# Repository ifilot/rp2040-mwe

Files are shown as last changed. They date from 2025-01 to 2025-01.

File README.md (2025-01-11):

# RP2040 Minimal Working Example

Slightly adjusted version of the [minimal design example](
https://datasheets.raspberrypi.com/rp2040/hardware-design-with-rp2040.pdf)
of Raspberry Pi LTD. Components have been added for the assembly service
of JLCPCB, choosing - where possible - as many basic components to save
costs.

BOM and placement files as well as the GERBER files are added available
for easy ordering.

> [!IMPORTANT]
> I did not design this PCB. I merely added the part IDs for JLCPCB and
> generated the BOM and CPL files. The original designs are made by
> Raspberry Pi LTD and it is highly recommended to always check their
> website for the latest version. See the link above.

## Files

* [GERBER files (zip)](RP2040_minimal_r2/GERBERS/RP2040_minimal.zip)
* [Bill of Materials](RP2040_minimal_r2/production/bom.csv)
* [Placement file](RP2040_minimal_r2/production/positions.csv)

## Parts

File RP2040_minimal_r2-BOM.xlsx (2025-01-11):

RP2040_minimal_r2 BOM
Item | Quantity | Reference | Part | Voltage | Current | Power | Material | Size | Tolerance | Manufacturer | Manuf. Part # | Description | Notes
1 | 3 | C1,C4,C17 | 10u | 16V |  |  | X5R | 0805_2012Metric | 10% | Murata | GRM21BR61C106KE15K | CAP CER 10UF 16V X5R 0805 | Or equivalent
2 | 2 | C2, C3 | 15p | 50V |  |  | C0G | 0402_1005Metric | 5% | Murata | GCM1555C1H150JA16D | CAP CER 15PF 50V C0G/NP0 0402 | Or equivalent
3 | 10 | C5, C6, C7, C9, C11, C12, C13, C14, C15, C16 | 100n | 25V |  |  | X7R | 0402_1005Metric | 10% | Murata | GRM155R71E104KE14J | CAP CER 0.1UF 25V X7R 0402 | Or equivalent
4 | 2 | C8, C10 | 1u | 10V |  |  | X6S | 0402_1005Metric | 10% | Murata | GRM155C81A105KA12D | CAP CER 1UF 10V X6S 0402 | Or equivalent
5 | 1 | J1 | USB_B_Micro |  |  |  |  |  |  | Amphenol | 10103594-0001LF | CONN RCPT USB2.0 MICRO B SMD R/A | Or equivalent
6 | 1 | J2 | 1x2 way header |  |  |  |  |  |  | Samtec | TSW-102-23-T-S | 2.54mm pin header 1x2 | Or equivalent
7 | 2 | J3, J4 | 2x18 way header |  |  |  |  |  |  | Samtec | TSW-118-23-T-D | 2.54mm pin header 2x18 | Or equivalent
8 | 2 | R1, R5 | 1k |  |  | 63mW |  | 0402_1005Metric | 1% | Yageo | RC0402FR-071KP | RES SMD 1K OHM 1% 1/16W 0402 | Or equivalent
9 | 1 | R2 | DNF |  |  |  |  | 0402_1005Metric |  |  |  |  | Do Not Fit
10 | 2 | R3, R4 | 27.4 |  |  | 63mW |  | 0402_1005Metric | 1% | Yageo | RC0402FR-0727R4L | RES SMD 27.4 OHM 1% 1/16W 0402 | Or equivalent
11 | 1 | U1 | NCP1117-3.3 |  |  |  |  | SOT-223-3 |  | ON Semiconductor | NCP1117ST33T3G | IC REG LINEAR 3.3V 1A SOT223
12 | 1 | U2 | W25Q128JVS |  |  |  |  | SOIC-8 |  | Winbond | W25Q128JVSIQ TR | IC FLASH 128M SPI 133MHZ 8SOIC
13 | 1 | U3 | RP2040 |  |  |  |  | QFN56 |  | Raspberry Pi | RP2040
14 | 1 | Y1 | ABM8-272-T3 |  |  |  |  | SMD_3225 |  | Abracon | ABM8-272-T3 | CRYSTAL 12.0000MHZ 3.2x2.5MM SMD

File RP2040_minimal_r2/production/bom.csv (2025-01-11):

Designator | Footprint | Quantity | Value | LCSC Part #
C1, C17, C4 | 0805 | 3 | 10u | C15850
C10, C8 | 0402 | 2 | 1u | C52923
C11, C12, C13, C14, C15, C16, C5, C6, C7, C9 | 0402 | 10 | 100n | C307331
C2, C3 | 0402 | 2 | 15p | C1548
J1 | USB_Micro-B_Amphenol_10103594-0001LF_Horizontal_modified | 1 | USB_B_Micro | C428495
R1, R5 | 0402 | 2 | 1k | C11702
R3, R4 | 0402 | 2 | 27 | C274349
U1 | SOT-223-3_TabPin2 | 1 | NCP1117-3.3_SOT223 | C26537
U2 | SOIC-8_5.23x5.23mm_P1.27mm | 1 | W25Q128JVS | C97521
U3 | RP2040-QFN-56 | 1 | RP2040 | C2040
Y1 | Crystal_SMD_3225-4Pin_3.2x2.5mm | 1 | ABM8-272-T3 | C20625731

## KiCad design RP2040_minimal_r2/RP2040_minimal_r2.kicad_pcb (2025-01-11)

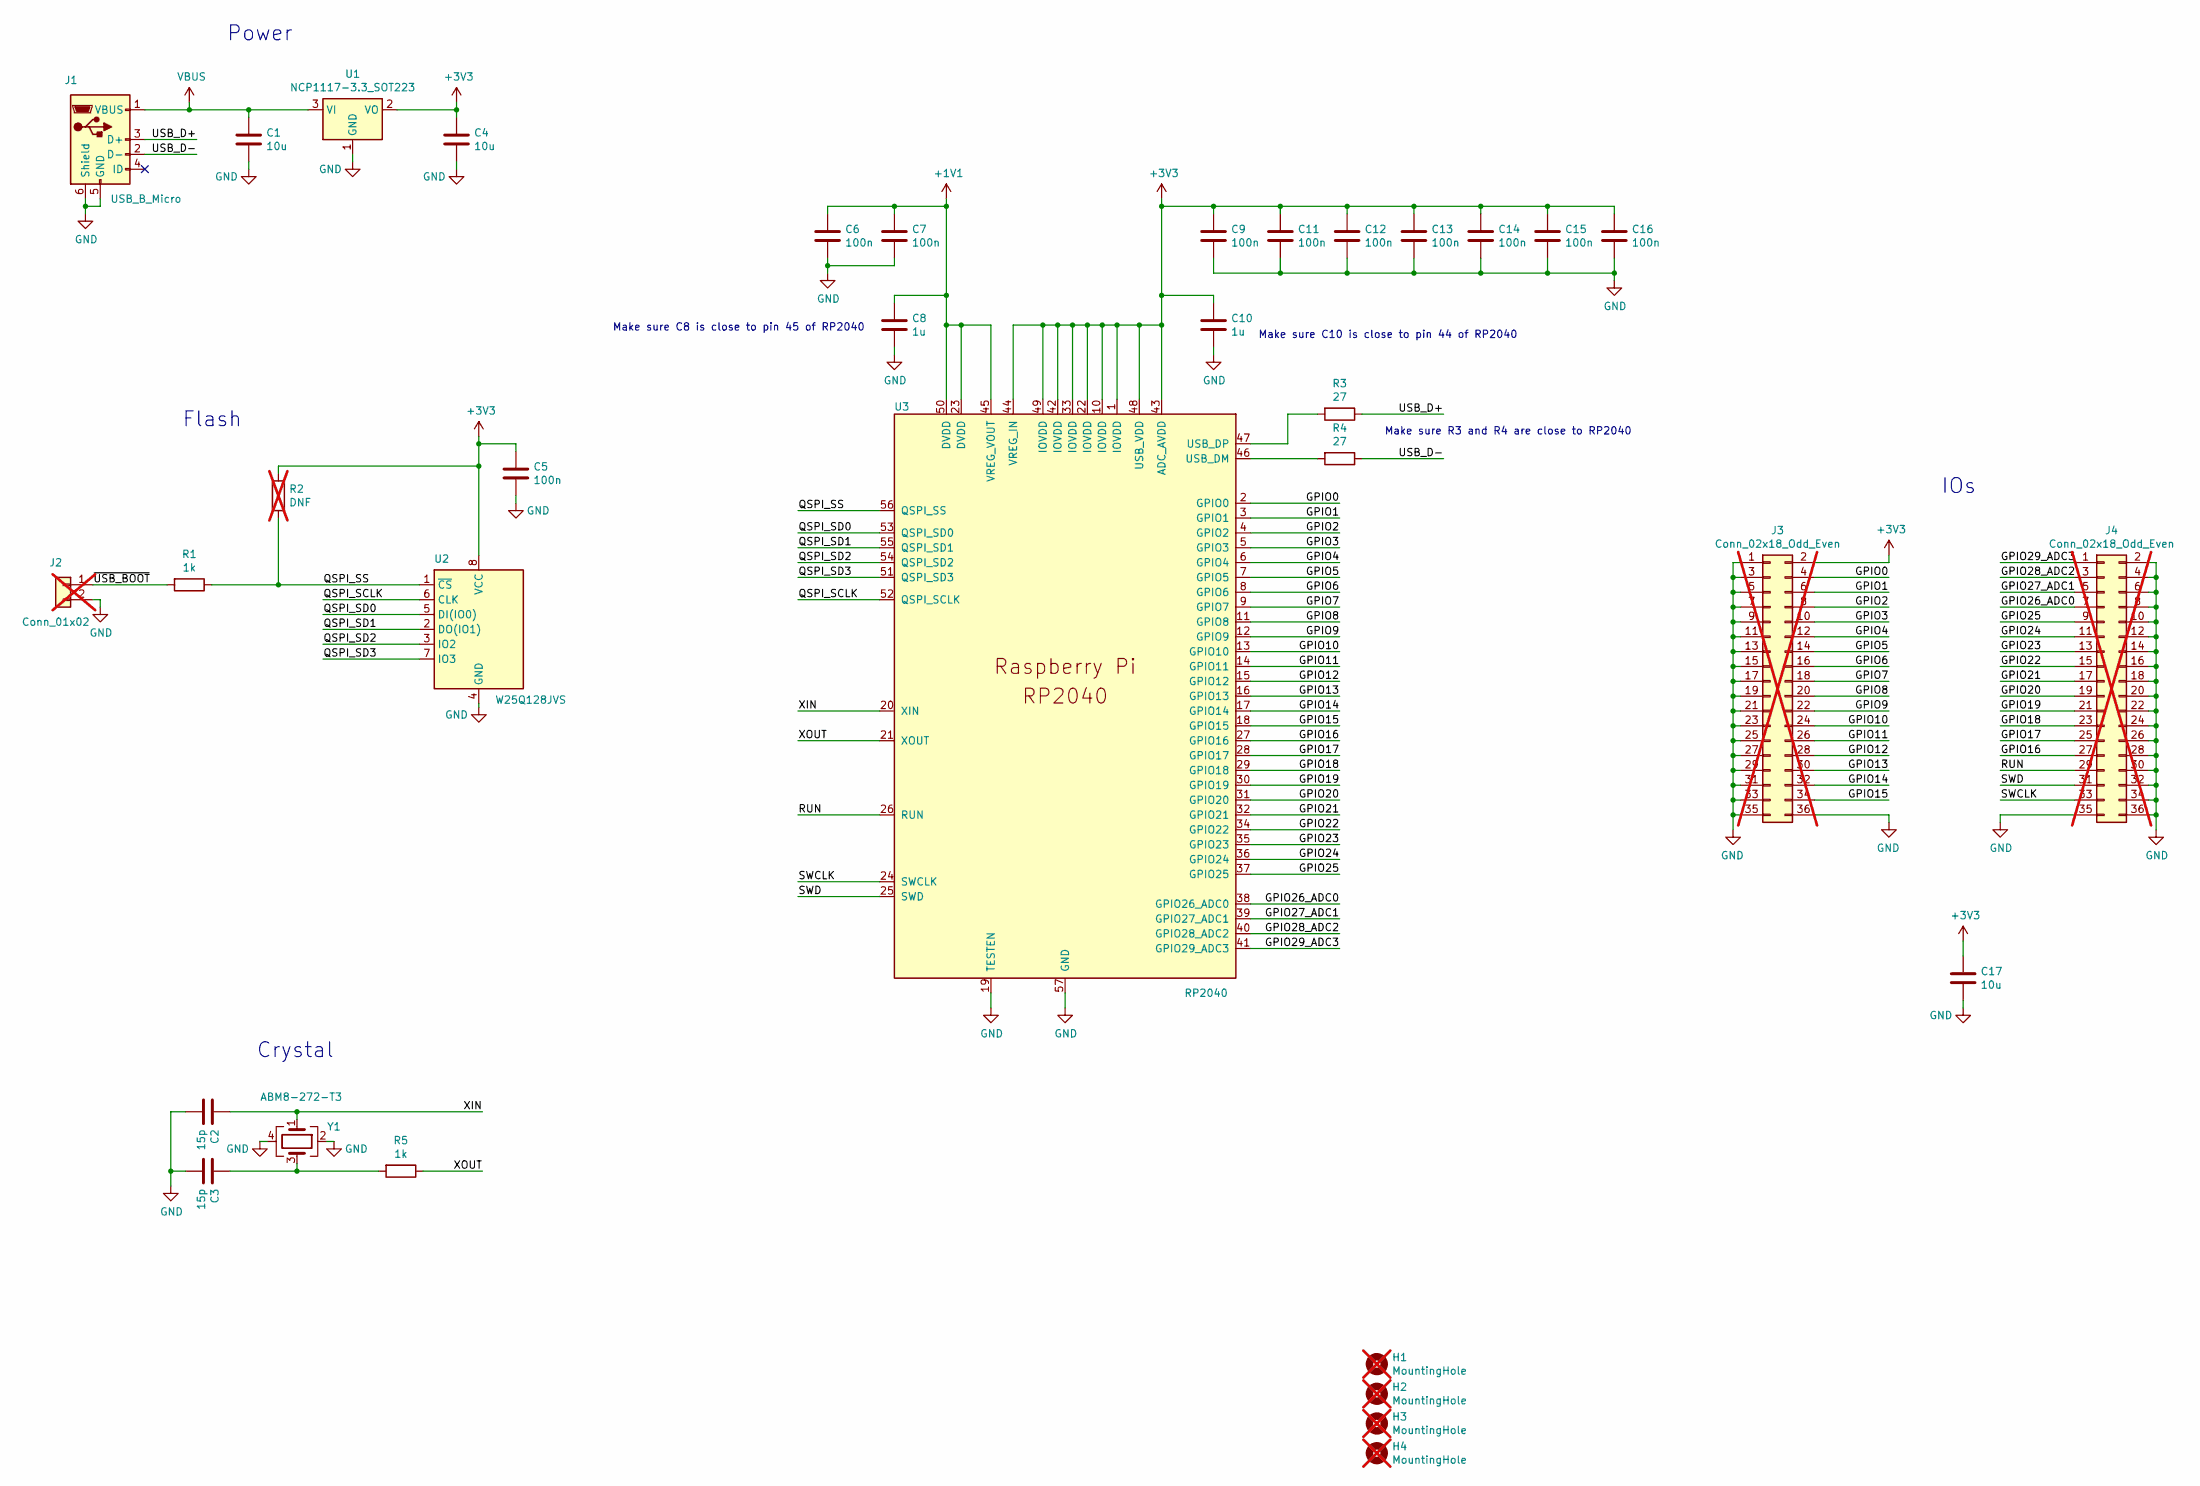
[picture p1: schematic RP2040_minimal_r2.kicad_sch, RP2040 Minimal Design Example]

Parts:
C1, C4, C17: 10u; C_0805_2012Metric; LCSC C15850
C2, C3: 15p; C_0402_1005Metric; LCSC C1548
C5, C6, C7, C9, C11, C12, C13, C14, C15, C16: 100n; C_0402_1005Metric; LCSC C307331
C8, C10: 1u; C_0402_1005Metric; LCSC C52923
H1, H2, H3, H4: MountingHole; MountingHole_2.7mm_M2.5; not fitted
J1: USB_B_Micro; USB_Micro-B_Amphenol_10103594-0001LF_Horizontal_modified; LCSC C428495
J2: Conn_01x02; PinHeader_1x02_P2.54mm_Vertical; not fitted
J3, J4: Conn_02x18_Odd_Even; PinHeader_2x18_P2.54mm_Vertical; not fitted
R1, R5: 1k; R_0402_1005Metric; LCSC C11702
R2: DNF; R_0402_1005Metric; not fitted
R3, R4: 27; R_0402_1005Metric; LCSC C274349
U1: NCP1117-3.3_SOT223; SOT-223-3_TabPin2; LCSC C6186
U2: W25Q128JVS; SOIC-8_5.23x5.23mm_P1.27mm; LCSC C97521
U3: RP2040; RP2040-QFN-56; LCSC C2040
Y1: ABM8-272-T3; Crystal_SMD_3225-4Pin_3.2x2.5mm; LCSC C20625731

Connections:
+1V1: C6.1, C7.1, C8.1, U3.23 (DVDD), U3.45 (VREG_VOUT), U3.50 (DVDD)
+3V3: C4.1, C5.1, C9.1, C10.1, C11.1, C12.1, C13.1, C14.1, C15.1, C16.1, C17.1, J3.2, R2.1, U1.2 (VO), U2.8 (VCC), U3.1 (IOVDD), U3.10 (IOVDD), U3.22 (IOVDD), U3.33 (IOVDD), U3.42 (IOVDD), U3.43 (ADC_AVDD), U3.44 (VREG_IN), U3.48 (USB_VDD), U3.49 (IOVDD)
/GPIO0: J3.4, U3.2 (GPIO0)
/GPIO1: J3.6, U3.3 (GPIO1)
/GPIO2: J3.8, U3.4 (GPIO2)
/GPIO3: J3.10, U3.5 (GPIO3)
/GPIO4: J3.12, U3.6 (GPIO4)
/GPIO5: J3.14, U3.7 (GPIO5)
/GPIO6: J3.16, U3.8 (GPIO6)
/GPIO7: J3.18, U3.9 (GPIO7)
/GPIO8: J3.20, U3.11 (GPIO8)
/GPIO9: J3.22, U3.12 (GPIO9)
/GPIO10: J3.24, U3.13 (GPIO10)
/GPIO11: J3.26, U3.14 (GPIO11)
/GPIO12: J3.28, U3.15 (GPIO12)
/GPIO13: J3.30, U3.16 (GPIO13)
/GPIO14: J3.32, U3.17 (GPIO14)
/GPIO15: J3.34, U3.18 (GPIO15)
/GPIO16: J4.27, U3.27 (GPIO16)
/GPIO17: J4.25, U3.28 (GPIO17)
/GPIO18: J4.23, U3.29 (GPIO18)
/GPIO19: J4.21, U3.30 (GPIO19)
/GPIO20: J4.19, U3.31 (GPIO20)
/GPIO21: J4.17, U3.32 (GPIO21)
/GPIO22: J4.15, U3.34 (GPIO22)
/GPIO23: J4.13, U3.35 (GPIO23)
/GPIO24: J4.11, U3.36 (GPIO24)
/GPIO25: J4.9, U3.37 (GPIO25)
/GPIO26_ADC0: J4.7, U3.38 (GPIO26_ADC0)
/GPIO27_ADC1: J4.5, U3.39 (GPIO27_ADC1)
/GPIO28_ADC2: J4.3, U3.40 (GPIO28_ADC2)
/GPIO29_ADC3: J4.1, U3.41 (GPIO29_ADC3)
/QSPI_SCLK: U2.6 (CLK), U3.52 (QSPI_SCLK)
/QSPI_SD0: U2.5 (DI(IO0)), U3.53 (QSPI_SD0)
/QSPI_SD1: U2.2 (DO(IO1)), U3.55 (QSPI_SD1)
/QSPI_SD2: U2.3 (IO2), U3.54 (QSPI_SD2)
/QSPI_SD3: U2.7 (IO3), U3.51 (QSPI_SD3)
/QSPI_SS: R1.1, R2.2, U2.1 (~CS), U3.56 (QSPI_SS)
/RUN: J4.29, U3.26 (RUN)
/SWCLK: J4.33, U3.24 (SWCLK)
/SWD: J4.31, U3.25 (SWD)
/USB_D+: J1.3 (D+), R3.1
/USB_D-: J1.2 (D-), R4.1
/XIN: C2.1, U3.20 (XIN), Y1.1
/XOUT: R5.1, U3.21 (XOUT)
/~USB_BOOT: J2.1, R1.2
GND: C1.2, C2.2, C3.2, C4.2, C5.2, C6.2, C7.2, C8.2, C9.2, C10.2, C11.2, C12.2, C13.2, C14.2, C15.2, C16.2, C17.2, J1.5 (GND), J1.6 (Shield), J2.2, J3.1, J3.3, J3.5, J3.7, J3.9, J3.11, J3.13, J3.15, J3.17, J3.19, J3.21, J3.23, J3.25, J3.27, J3.29, J3.31, J3.33, J3.35, J3.36, J4.2, J4.4, J4.6, J4.8, J4.10, J4.12, J4.14, J4.16, J4.18, J4.20, J4.22, J4.24, J4.26, J4.28, J4.30, J4.32, J4.34, J4.35, J4.36, U1.1 (GND), U2.4 (GND), U3.19 (TESTEN), U3.57 (GND), Y1.2, Y1.4
unnamed: C3.1, R5.2, Y1.3
unnamed: R4.2, U3.46 (USB_DM)
unnamed: R3.2, U3.47 (USB_DP)
VBUS: C1.1, J1.1 (VBUS), U1.3 (VI)

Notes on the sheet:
IOs
Power
Crystal
Make sure C8 is close to pin 45 of RP2040
Make sure C10 is close to pin 44 of RP2040
Make sure R3 and R4 are close to RP2040
Flash


Board: 2 copper layers, 52.0 x 51.0 mm, 34 parts (0 on the bottom side), 51 nets.
